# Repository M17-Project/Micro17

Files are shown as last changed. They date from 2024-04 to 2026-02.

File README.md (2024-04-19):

[][cc-by-nc-sa]

# Micro17
M17 baseband processor board - OpenRTX on a Module.
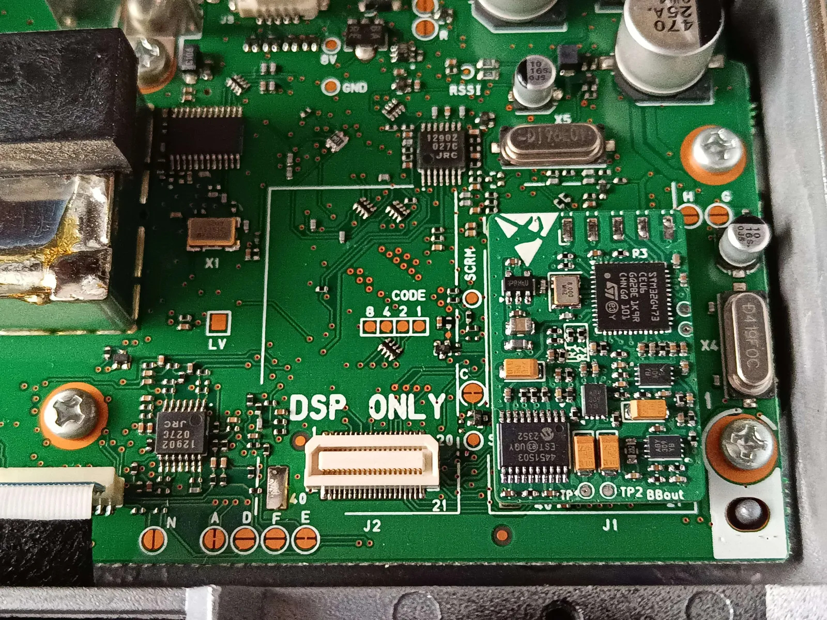
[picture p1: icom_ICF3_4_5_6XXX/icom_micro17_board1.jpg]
Micro17 connected to an ICOM radio.


## What is this?
Micro17 is an integrated implementation of Module17. Its PCB design is radio-dependent, but the general schematic is quite close to Module17. 
For more info about M17 and Module17, please checkout [M17's Website](https://m17project.org/) and [Module17's Github](https://github.com/M17-Project/Module_17) .

## Supported radios - variants
|Brand/Models|Status|
|---|---|
|[Generic (for all radios, can be used with modwires)](/generic/)|Hardware design WIP|
|[ICOM IC-F3XXX/4XXX/5XXX/6XXX](/icom_ICF3_4_5_6XXX/)|PoC OK, hardware design finished, fw WIP|
|[Motorola Waris (GM340/360/etc.)](/moto_waris/)|PoC OK, hardware design WIP|

## Adding support for other models
Do you have a radio that could be compatible with such an implementation? 
Any header (or ribbon cable connector) inside with the following pins can be used:
 - Flat audio in/out
 - Micro/Speaker lines
 - PTT in/out
 - Power supply 
 - (nice to have) command lines for interfacing with the radio's CPU
 
Very often, commercial radios with a scrambling board option have such lines inside. A Module17 modem is a perfect base to test a Proof of Concept before starting hardware design.
When creating a new variant of Micro17, you can use the "generic" variant as a working base, just copy and rename that folder.

## License
This work is licensed under a
[Creative Commons Attribution-NonCommercial-ShareAlike 4.0 International License][cc-by-nc-sa].

[][cc-by-nc-sa]

[cc-by-nc-sa]: http://creativecommons.org/licenses/by-nc-sa/4.0/
[cc-by-nc-sa-image]: https://licensebuttons.net/l/by-nc-sa/4.0/88x31.png
[cc-by-nc-sa-shield]: https://img.shields.io/badge/License-CC%20BY--NC--SA%204.0-lightgrey.svg

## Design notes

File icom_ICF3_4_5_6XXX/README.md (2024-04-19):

# Micro17 - IC-F3/4/5/6X6X
Variant of Micro17 for ICOM IC-F commercial radios. Compatible model list is available [here](/icom_ICF3_4_5_6XXX/general_info.md).
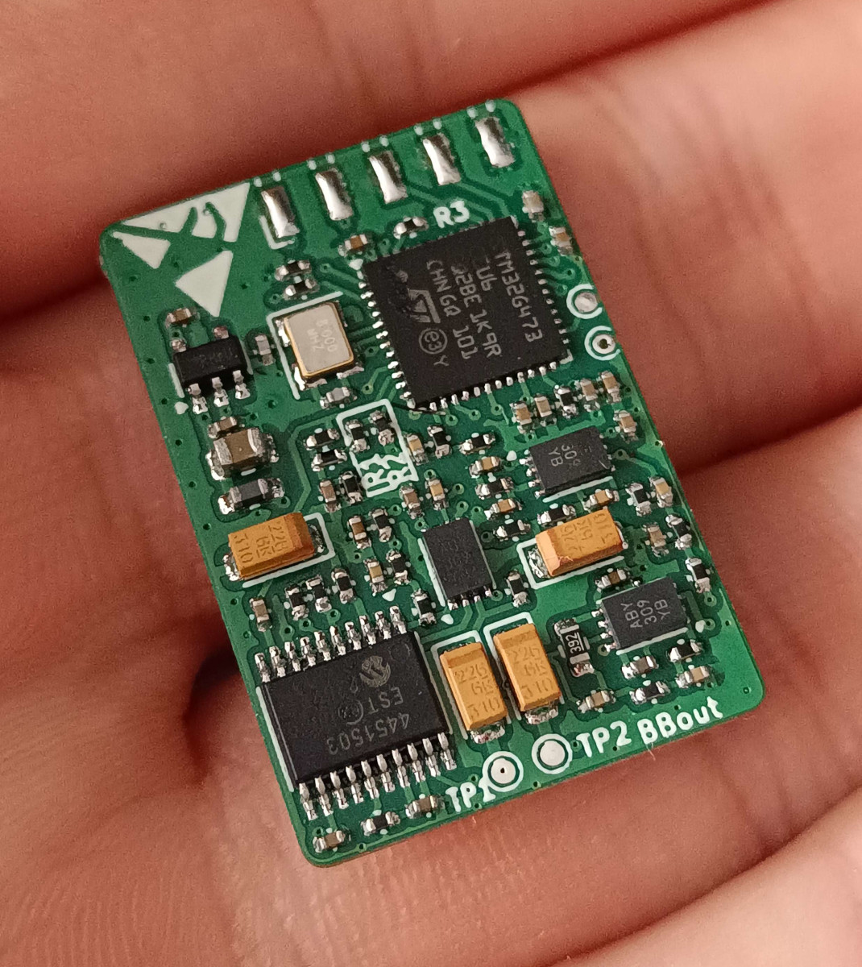
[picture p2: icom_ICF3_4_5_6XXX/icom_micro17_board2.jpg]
Micro17 connected to an ICOM radio.

## Flashing OpenRTX
WIP - ST-Link needed

## Installing Micro17 inside the radio
A Youtube video guide is planned soon:tm:. 
### Mobiles
Getting inside mobile IC-F5X6X/6X6X is quite straightforward: four screws will allow you to pop the bottom cover off. 
You'll need to cut/solder the following bridges:
* Cut "K", "A", "B" and "C"
* Solder/bridge "L"

You can then install Micro17 in the J1 slot. 
Micro17 connected to an ICOM radio.
### Handsets
Opening a handset is a bit trickier. You'll need to remove the two knobs, unscrew the antenna nut (either using thin needle-nose pliers or the appropriate tool. Be careful as it might be glued, some light blasting with a heat gun might be needed) and the two bottom screws behind the battery. 
The following bridges will have to be changed: 
* Cut "CP2", "MIC", "AFOUT" and "PTT" 
* Solder/bridge  "CP3"
You can then install Micro17 in the J1 slot.

## Configuring Micro17
As this module is embedded inside the radio, configuration is pulled from the radio's "codeplug". This is still heavily WIP, but it's planned to use the internal command protocol one the details get figured out. 

## Wiring details
This variant is based on the experiments documented [here](https://wiki.m17project.org/icf5060_3060). 
The internal J1 connector breaks out all necessary pins.
| **Module17 equivalent Pins** | **J1 connector** |
|---|---|
| GND (DB9 - pin 8) | Pin 2, 17 or 39 - GND |
| +12V/+8V (DB9 - pin 9) | Pin 37 - VCC |
| RX (DB9 - pin 6) | Pin 31 - DISC |
| TX (DB9 - pin 2) | Pin 13 - SIGO |
| PTT_OUT (DB9 - pin 5) | Pin 4 - PTTO (Add a 1K pullup to 5V - pin 38!) |
| AF_OUT (pot middle pin) | Pin 30 - AFOUT |
| MIC_IN (jack's middle pin) | Pin 7 - MCIN |
| PTT_IN (jack's last pin) | Pin 3 - PTTIN (Through a resistive divider: two 2.7k resistors in series between pins 2 and 3, wire to Module17 in the middle) |

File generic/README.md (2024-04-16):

# Micro17 - Generic

Generic variant of Micro17 for any radio.
This is still a simple copy of the ICOM version of this board. Just don't place the connector and solder to the test pads. 

## Flashing OpenRTX
WIP - ST-Link needed

## Installing Micro17 inside the radio
All up to you! Kynar modwires will be your best friend here.

## Configuring Micro17
As this module is embedded inside the radio, you'll have to either statically set your callsign inside the radio, or figure out a way to pull data from the radio's "codeplug"

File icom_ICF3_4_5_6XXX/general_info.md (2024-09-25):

# General information on ICOM IC-FXX6X radios
Almost every variation of the IC-FXX6X should be compatible with Micro17. 

## Model numbering
The model number will help you in identifying which version you have.
It is composed of 4 digits and one or more letters.
### First digit
* 5: Mobile VHF
* 6: Mobile UHF
* 3: Handset VHF
* 6: Handset UHF
  
### Second digit
* 0: compatible
* 1: compatible
* 2: __completely different revision, not compatible__

### Third digit
Only 6 is compatible

### Fourth digit
Market segment: 
* 1: USA
* 2: European Market
* 3: General
  
Be careful as there are US market models (suffix "1") that are 450-520, and others 400-470. I've managed to bring 450 models down to 434MHz, but it makes things quite complicated. Identifying them requires checking the FCC ID in the database, it'll give you the frequency range (handset numbers AFJ289402: 450-520MHz, AFJ289401: 400-470MHz). 

### Letter suffixes:
* T: 10-key version
* S: for a 4 key version
* D: digital (with an additional UT-126 board for NXDN and dPMR support. Basically the exact same radio with an additional removable board).
  
A 4-key version can be case-swapped with a 10 key version without issues. The UT-126 is completely unnecessairy for this M17 mod. Removing it might be a good idea to reduce battery usage. 

### Common examples
In UHF, the IC-F6061 mobile is quite common on eBay. If you're in Europe, you might get lucky and score an IC-F6062. For handsets, the IC-F4161DS pops up a lot.

## Programming the radios
Those radios are channelized, and will require you to program your frequencies one way or another. If you're lucky, you'll be able to program it via the front panel [using this procedure](https://sawback.com/wp-content/uploads/2018/11/Icom-Front-Panel-Programming.pdf) (the combination to trigger programming mode is slightly different: P0 and the button above PTT). 
Otherwise, you'll need the cloning software (a quick google search should help you out) and the programming cable:
* For the handsets, you'll need to buy the cable, cheap clones are available on [Aliexpress](https://www.aliexpress.com/item/1005001671445899.html).
* For the mobiles, Aliexpress can also be your friend... You can also make your own cable using an RJ45 connector and a 5V USB-TTL adapter. Pin 2 goes to RXD, Pin 8 to TXD, Pin 7 to GND.

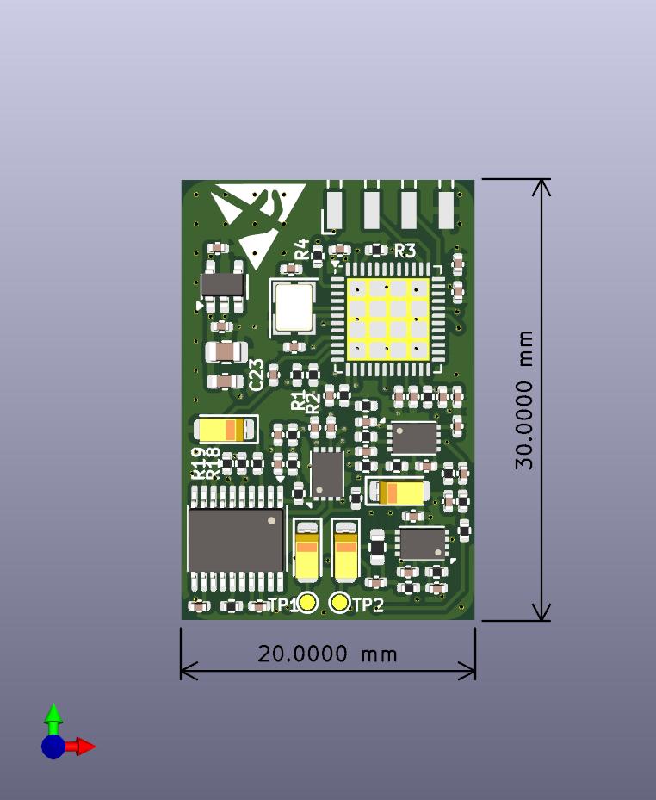
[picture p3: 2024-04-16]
generic/icom_micro17_design.jpg

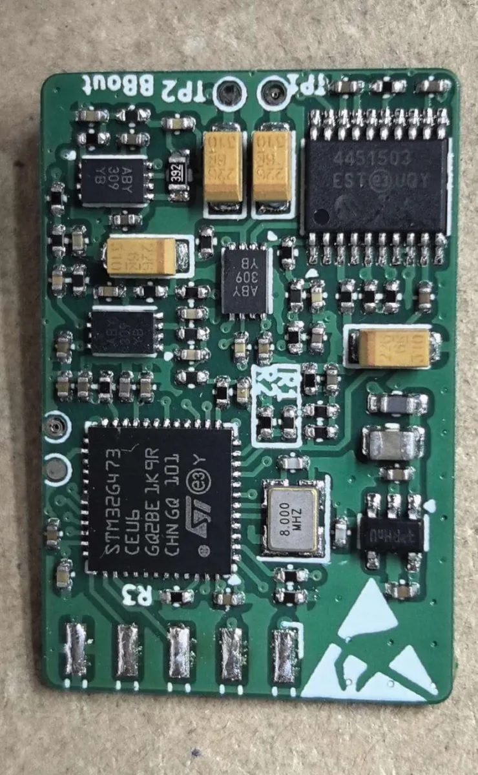
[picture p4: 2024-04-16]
generic/icom_micro17_board2.jpg

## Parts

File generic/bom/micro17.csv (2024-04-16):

Id | Designator | Footprint | Quantity | Designation | Supplier and ref
1 | R13,R23 | R_0402_1005Metric | 2 | 39k
2 | C19,C31,C20,C24,C29,C16,C14,C15 | C_0402_1005Metric | 8 | 10n
3 | R29,R2 | R_0402_1005Metric | 2 | 12k
4 | C28,C34,C26,C27 | CP_EIA-3216-18_Kemet-A | 4 | 22u
5 | R1 | R_0402_1005Metric | 1 | 36k
6 | R10,R11 | R_0402_1005Metric | 2 | 7k5
7 | U2 | SOT-23-5 | 1 | XC6220B331MR
8 | R5 | R_0402_1005Metric | 1 | 10R
9 | R27,R20,R21,R17,R28,R26 | R_0402_1005Metric | 6 | 22k
10 | R16,R4,R3 | R_0402_1005Metric | 3 | 10k
11 | R9,R8 | R_0402_1005Metric | 2 | 13k
12 | C17,C18 | C_0402_1005Metric | 2 | 1n5
13 | C7,C13,C30,C6,C8,C35,C4,C5,C11,C33,C25 | C_0402_1005Metric | 11 | 100n
14 | R24 | R_0603_1608Metric | 1 | 3k9
15 | C12,C23,C22 | C_0402_1005Metric | 3 | 220n
16 | R14,R22,R19,R18 | R_0402_1005Metric | 4 | 3k3
17 | C32,C21 | C_0402_1005Metric | 2 | 680p
18 | U6,U4,U7 | DFN-8-1EP_3x2mm_P0.5mm_EP1.75x1.45mm | 3 | MCP6002
19 | C3 | C_0402_1005Metric | 1 | 2u2
20 | C2,C1 | C_0402_1005Metric | 2 | 2p2
21 | U5 | TSSOP-20_4.4x6.5mm_P0.65mm | 1 | MCP4451-503-ST
22 | C10 | C_0805_2012Metric | 1 | 22u/25V
23 | U1 | QFN-48-1EP_7x7mm_P0.5mm_EP5.6x5.6mm | 1 | STM32G473CCUx
24 | C9 | C_0402_1005Metric | 1 | 1u
25 | R12 | R_0402_1005Metric | 1 | 3k9
26 | FB1 | L_0603_1608Metric_Pad1.05x0.95mm_HandSolder | 1 | FerriteBead_Small
27 | Y1 | Crystal_SMD_3225-4Pin_3.2x2.5mm | 1 | 8 MHz
28 | R15 | R_0402_1005Metric | 1 | 2k2
29 | R6,R7 | R_0402_1005Metric | 2 | 4k3
30 | J2 | AXK640347YG | 1 | AXK640347YG

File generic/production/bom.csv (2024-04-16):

Designator | Footprint | Quantity | Value | LCSC Part #
C1, C2 | 0402 | 2 | 2p2 | C1559
C10 | 0805 | 1 | 22u/25V | C45783
C11, C13, C25, C30, C33, C35, C4, C5, C6, C7, C8 | 0402 | 11 | 100n | C56392
C12, C22, C23 | 0402 | 3 | 220n | C192432
C14, C15, C16, C19, C20, C24, C29, C31 | 0402 | 8 | 10n | C60133
C17, C18 | 0402 | 2 | 1n5 | C284989
C21, C32 | 0402 | 2 | 680p | C1541
C26, C27, C28, C34 | CP_EIA-3216-18_Kemet-A | 4 | 22u | C118989
C3 | 0402 | 1 | 2u2 | C170151
C9 | 0402 | 1 | 1u | C29266
FB1 | 0603 | 1 | FerriteBead_Small | C2971885
J2 | AXK640347YG | 1 | AXK640347YG | C2936870
R1 | 0402 | 1 | 36k | C4354982
R10, R11 | 0402 | 2 | 7k5 | C2960875
R12 | 0402 | 1 | 3k9 | C3015806
R13, R23 | 0402 | 2 | 39k | C25783
R14, R18, R19, R22 | 0402 | 4 | 3k3 | C25890
R15 | 0402 | 1 | 2k2 | C102890
R16, R3, R4 | 0402 | 3 | 10k | C102749
R17, R20, R21, R26, R27, R28 | 0402 | 6 | 22k | C2909337
R2, R29 | 0402 | 2 | 12k | C25752
R24 | 0603 | 1 | 3k9 | C23018
R5 | 0402 | 1 | 10R | C854481
R6, R7 | 0402 | 2 | 4k3 | C25899
R8, R9 | 0402 | 2 | 13k | C25754
U1 | QFN-48-1EP_7x7mm_P0.5mm_EP5.6x5.6mm | 1 | STM32G473CCUx | C1342773
U2 | SOT-23-5 | 1 | XC6220B331MR | C3040644
U4, U6, U7 | DFN-8-1EP_3x2mm_P0.5mm_EP1.75x1.45mm | 3 | MCP6002 | C623660
U5 | TSSOP-20_4.4x6.5mm_P0.65mm | 1 | MCP4451-503-ST | C627257
Y1 | Crystal_SMD_3225-4Pin_3.2x2.5mm | 1 | 8 MHz | C5308002

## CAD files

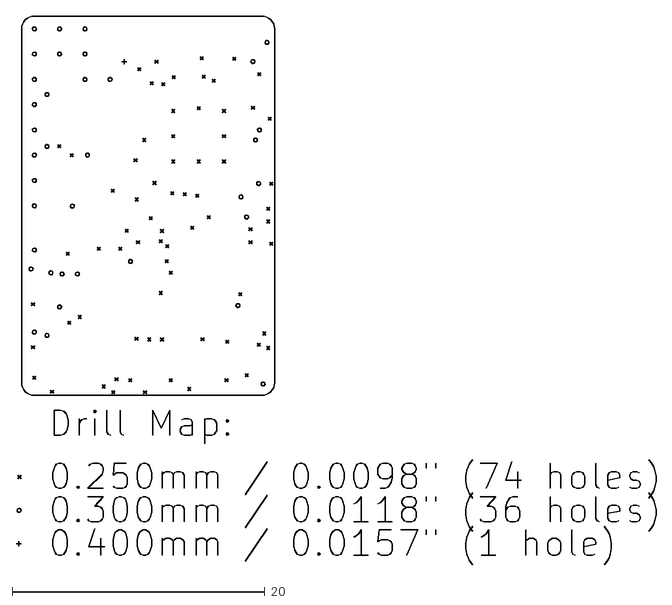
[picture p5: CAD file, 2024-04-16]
generic/Gerbers/micro17-PTH-drl_map.dxf
50.6 x 43.4

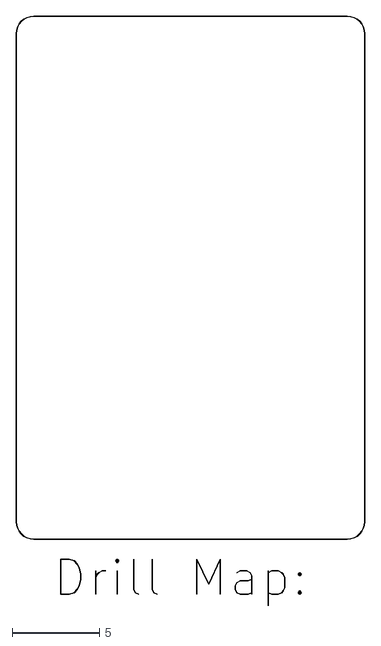
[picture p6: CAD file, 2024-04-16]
generic/Gerbers/micro17-NPTH-drl_map.dxf
20.0 x 33.8

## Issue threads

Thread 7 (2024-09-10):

DAC doesn't work - stuck at 0V

sp5wwp, 2024-09-10:
`VREF+` pin is left floating. Connect it with `VDDA`.

Workaround: put a solder blob across pins 20 and 21.

sp5wwp, 2025-06-13:
Fixed in [005c063](https://github.com/M17-Project/Micro17/commit/005c063634e73d94ec628afa24ce1d9f97f03a83).

Closed 2025-06-13.

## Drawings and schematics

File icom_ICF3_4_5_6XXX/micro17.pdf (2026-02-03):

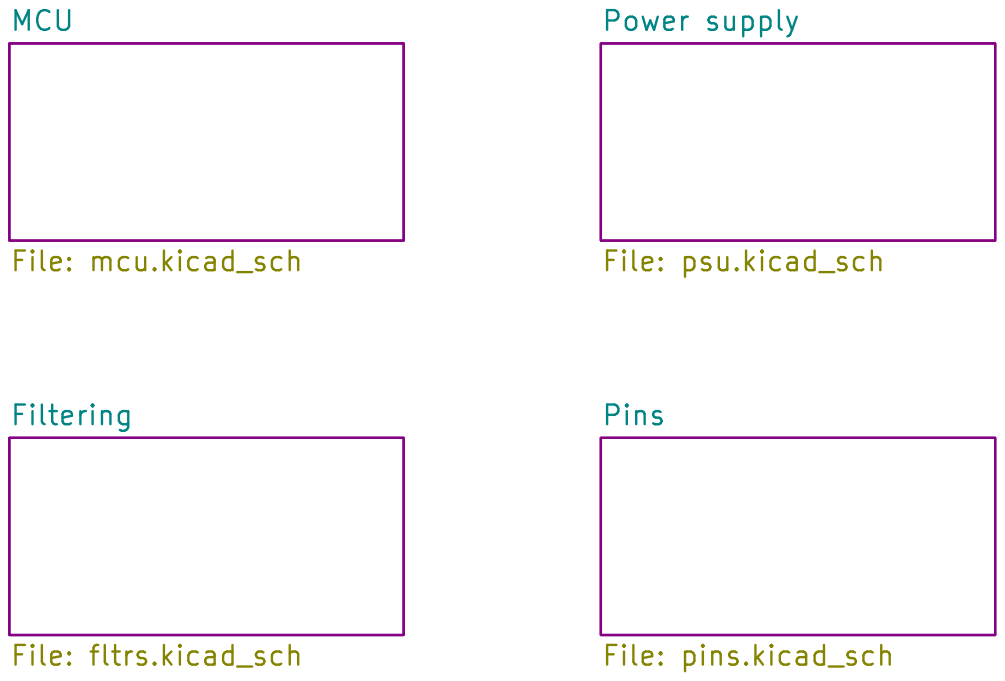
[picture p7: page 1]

Power supply File: psu.kicad_sch Pins File: pins.kicad_sch

Filtering File: fltrs.kicad_sch MCU

Id: 1/5 Title: Micro17 - OpenRTX on a Module for ICOM radios

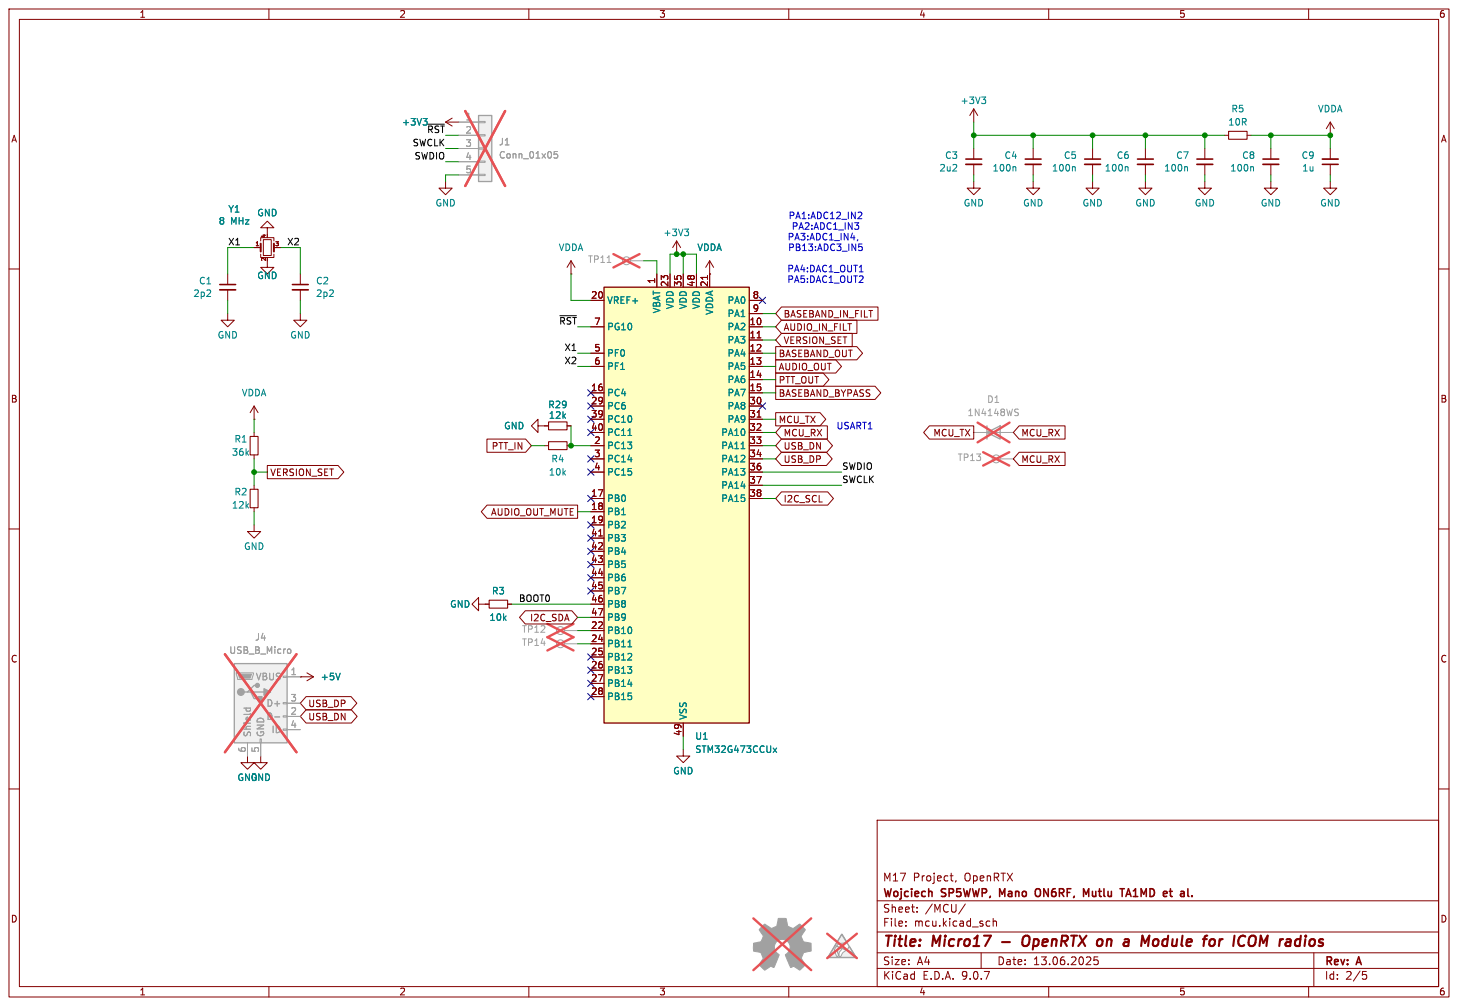
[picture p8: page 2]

1 VDD 23 VDD 35 VSS 49 VDD 48 VDDA 21 PA0 8 PA1 9 PA2 10 PA3 11 PA4 12 PA5 13 PA6 14 PA7 15 PA8 30 PA9 31 PA10 32 PA11 33 PA12 34 PA13 36 PA14 37 PA15 38 U1STM32G473CCUx D1

1 VDD 23 VDD 35 VSS 49 VDD 48 VDDA 21 PA0 8 PA1 9 PA2 10 PA3 11 PA4 12 PA5 13 PA6 14 PA7 15 PA8 30 PA9 31 PA10 32 PA11 33 PA12 34 PA13 36 PA14 37 PA15 38 GND

Id: 2/5 Title: Micro17 - OpenRTX on a Module for ICOM radios

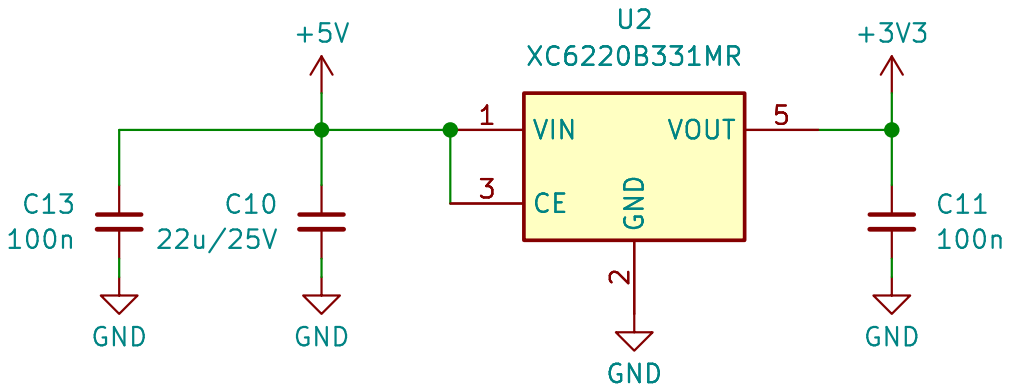
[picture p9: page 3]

Id: 3/5 Title: Micro17 - OpenRTX on a Module for ICOM radios

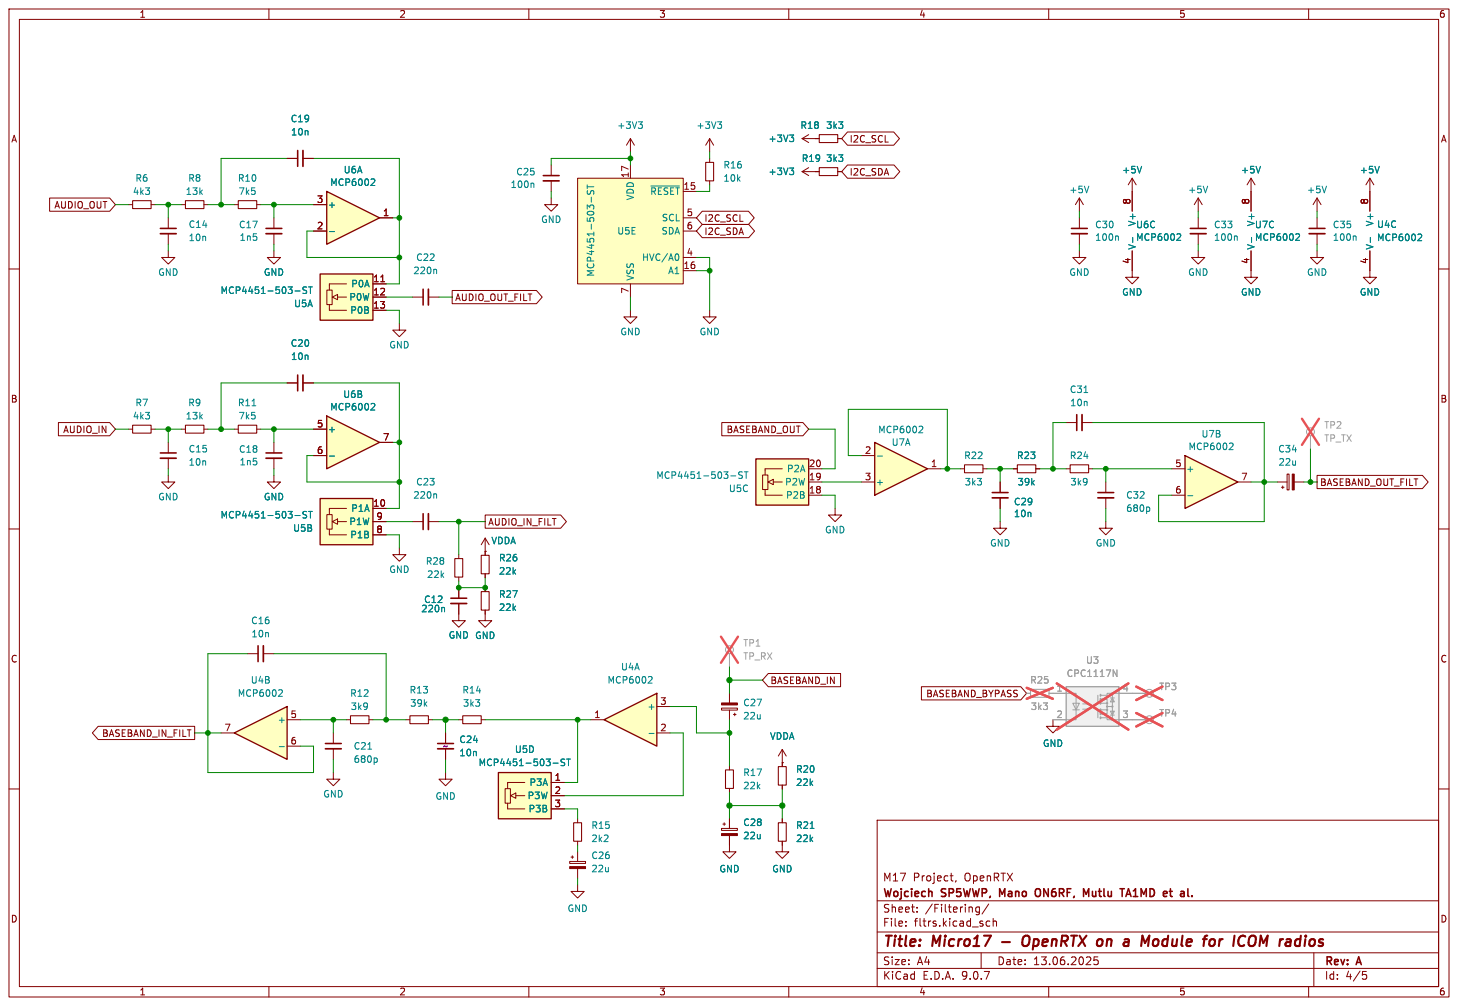
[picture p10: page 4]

File: fltrs.kicad_sch Sheet: /Filtering/
Id: 4/5 Title: Micro17 - OpenRTX on a Module for ICOM radios

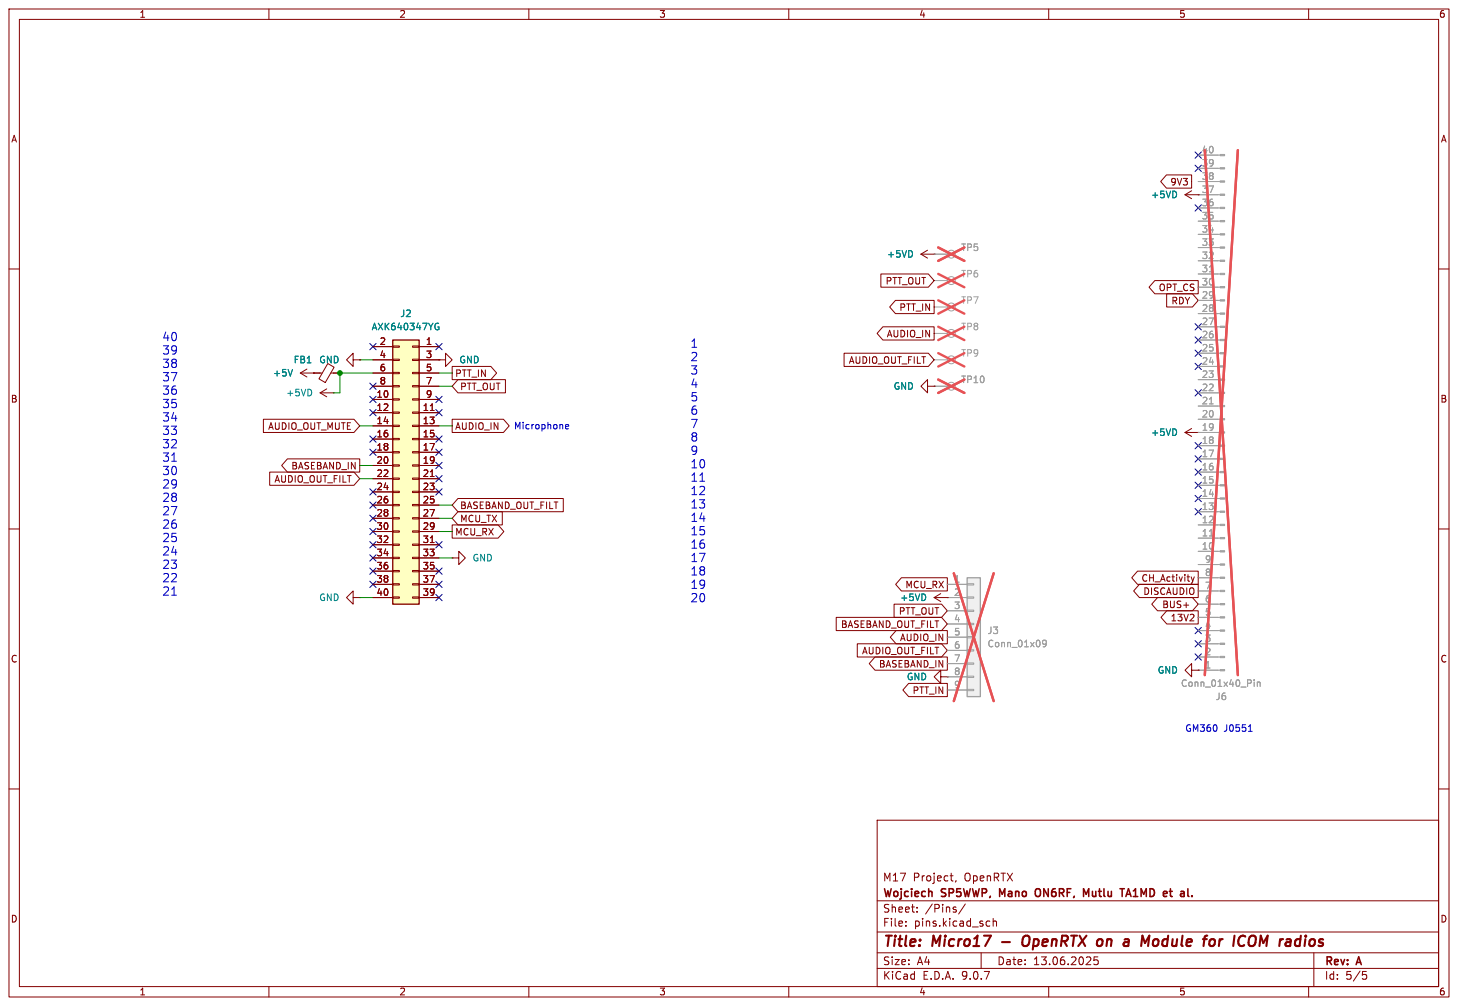
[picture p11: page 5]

Id: 5/5 Title: Micro17 - OpenRTX on a Module for ICOM radios

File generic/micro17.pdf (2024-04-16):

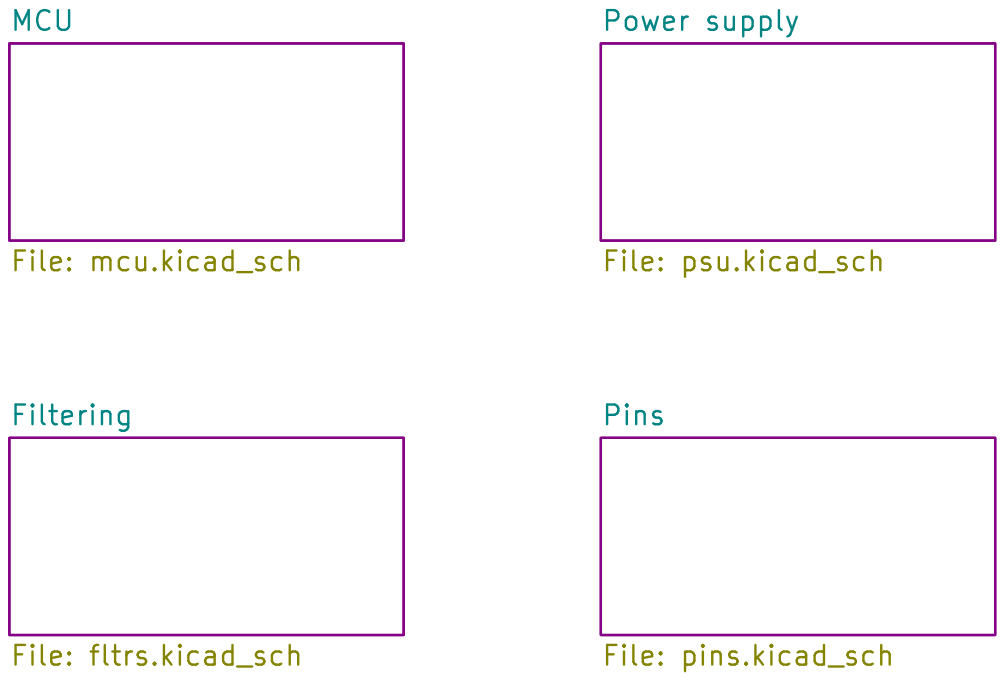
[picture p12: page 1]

Power supply File: psu.kicad_sch Pins File: pins.kicad_sch

Filtering File: fltrs.kicad_sch MCU

Id: 1/5 Title: Micro17 - OpenRTX on a Module for ICOM radios

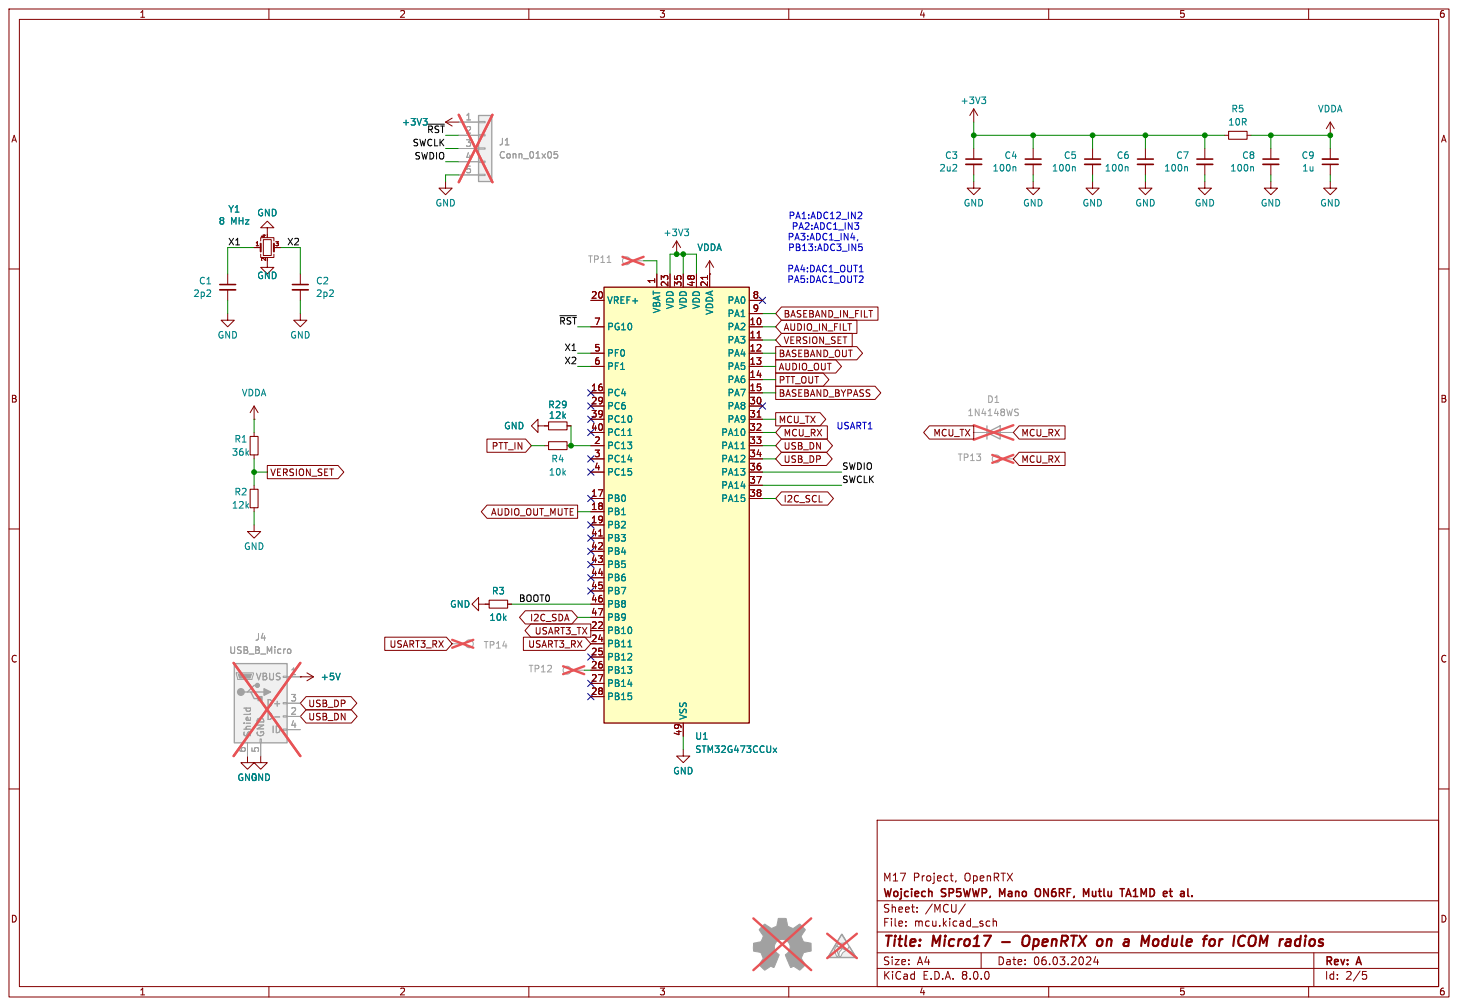
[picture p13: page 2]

1 PA2 10 PA3 11 PA4 12 PA5 13 PA6 14 PA7 15 PC4 16 PB0 17 PB1 18 PB2 19 PC13 2 VREF+ 20 VDDA 21 PB10 22 VDD 23 PB11 24 PB12 25 PB13 26 PB14 27 PB15 28 PC6 29 PC14 3 PA8 30 PA9 31 PA10 32 PA11 33 PA12 34 VDD 35 PA13 36 PA14 37 PA15 38 PC10 39 PC15 4 PC11 40 PB3 41 PB4 42 PB5 43 PB6 44 PB7 45 PB8 46 PB9 47 VDD 48 VSS 49 PF0 5 PF1 6 PG10 7 PA0 8 PA1 9 U1STM32G473CCUx R4

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

Id: 2/5 Title: Micro17 - OpenRTX on a Module for ICOM radios

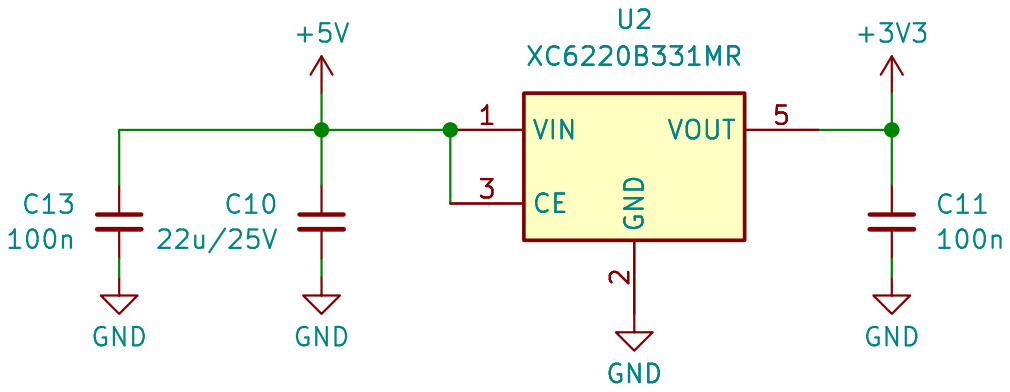
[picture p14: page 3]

Id: 3/5 Title: Micro17 - OpenRTX on a Module for ICOM radios

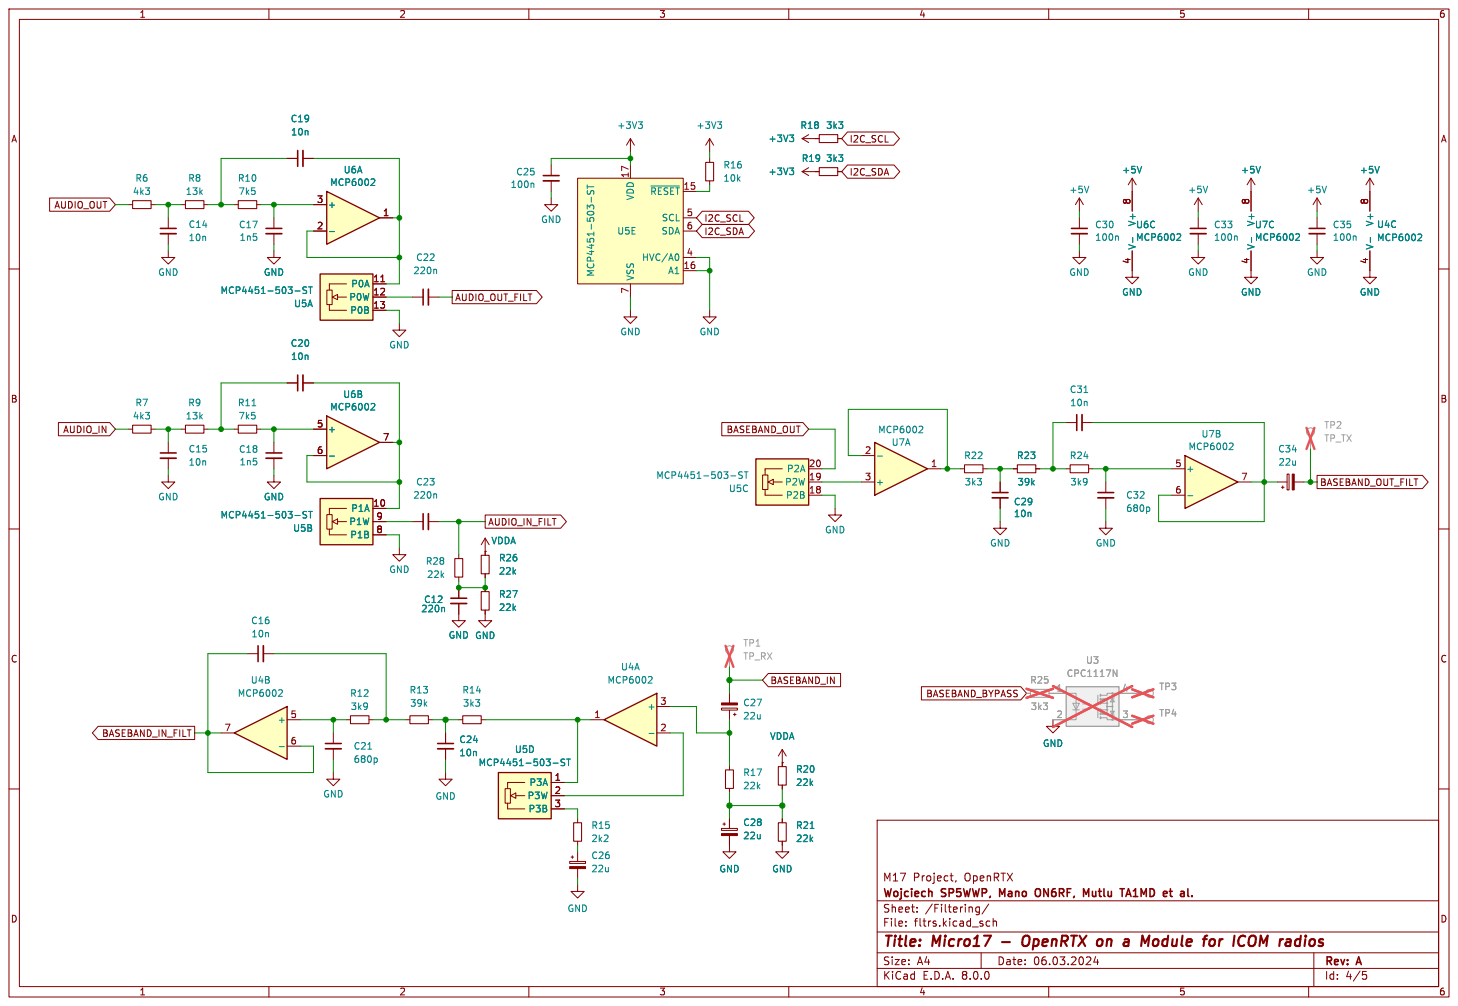
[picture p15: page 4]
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

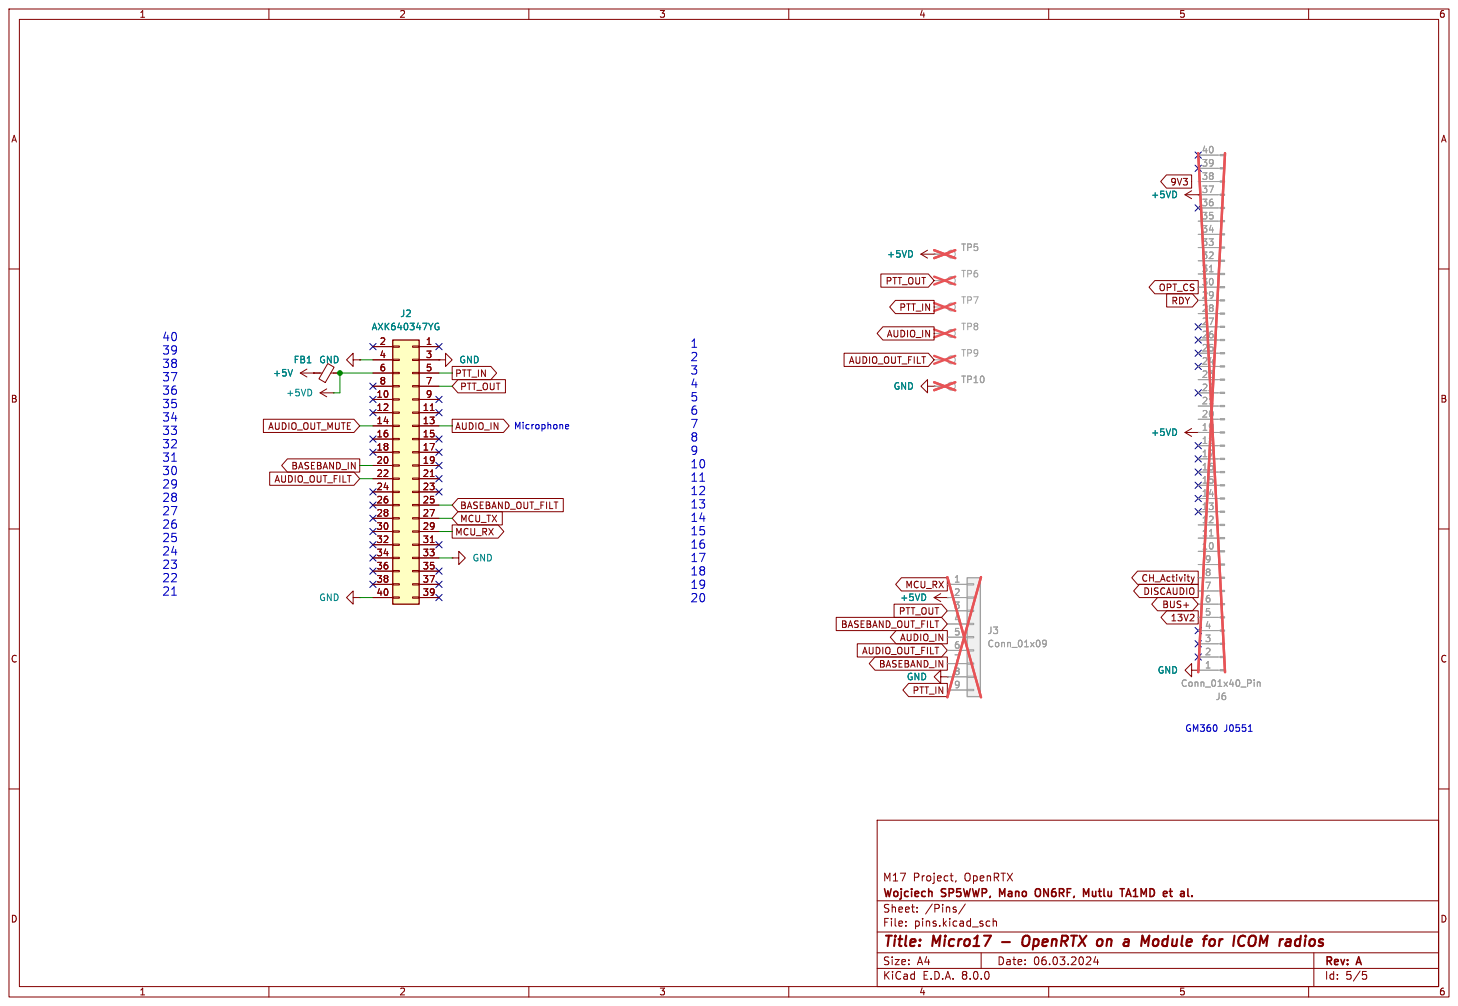
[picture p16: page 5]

Id: 5/5 Title: Micro17 - OpenRTX on a Module for ICOM radios

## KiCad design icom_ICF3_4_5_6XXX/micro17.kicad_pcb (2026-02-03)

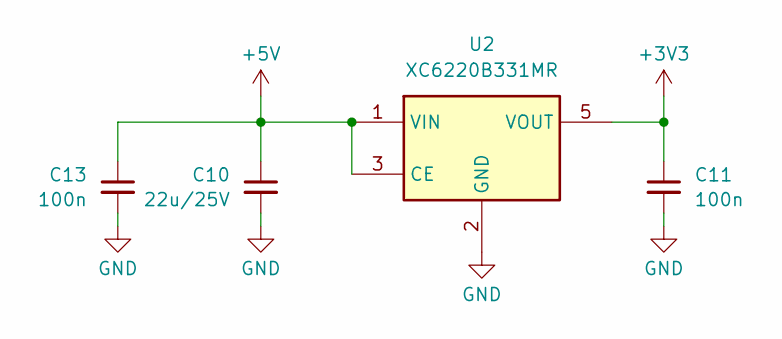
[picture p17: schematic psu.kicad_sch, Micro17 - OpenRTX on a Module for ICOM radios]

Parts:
C10: 22u/25V; C_0805_2012Metric; MPN C45783; LCSC C45783
C11, C13: 100n; C_0402_1005Metric; MPN C56392; LCSC C56392
U2: XC6220B331MR; SOT-23-5; MPN C3040644; LCSC C3040644

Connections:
+3V3: C11.1, U2.5 (VOUT); also elsewhere on the board
+5V: C10.1, C13.1, U2.1 (VIN), U2.3 (CE); also elsewhere on the board
GND: C10.2, C11.2, C13.2, U2.2 (GND); also elsewhere on the board

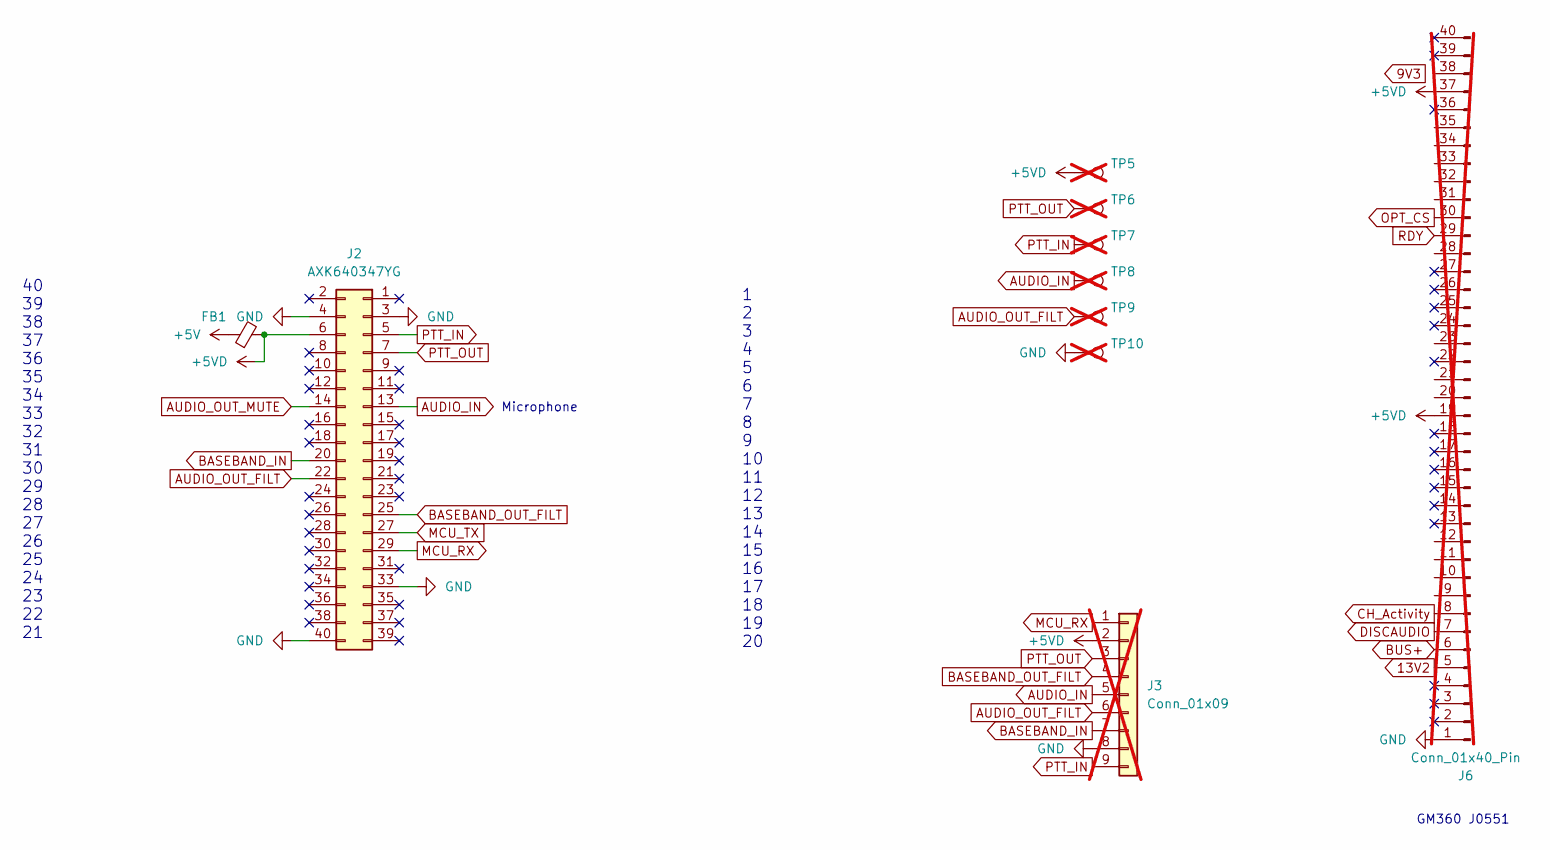
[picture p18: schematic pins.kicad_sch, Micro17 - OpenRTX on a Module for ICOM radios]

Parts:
FB1: FerriteBead_Small; L_0603_1608Metric_Pad1.05x0.95mm_HandSolder; MPN C2971885; LCSC C2971885
J2: AXK640347YG; MPN C2936870; LCSC C2936870
J3: Conn_01x09; PinSocket_1x09_P2.00mm_Horizontal; not fitted
J6: Conn_01x40_Pin; Hirose_FH12-40S-0.5SH_1x40-1MP_P0.50mm_Horizontal; not fitted
TP5, TP6, TP7, TP8, TP9, TP10: GP; TestPoint_Pad_D1.0mm; not fitted

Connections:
+5V: FB1.1; also elsewhere on the board
+5VD: FB1.2, J2.6, J3.2, J6.19, J6.37, TP5.1
AUDIO_IN: J2.13, J3.5, TP8.1; also elsewhere on the board
AUDIO_OUT_FILT: J2.22, J3.6, TP9.1; also elsewhere on the board
AUDIO_OUT_MUTE: J2.14; also elsewhere on the board
BASEBAND_IN: J2.20, J3.7; also elsewhere on the board
BASEBAND_OUT_FILT: J2.25, J3.4; also elsewhere on the board
GND: J2.3, J2.4, J2.33, J2.40, J3.8, J6.1, TP10.1; also elsewhere on the board
MCU_RX: J2.29, J3.1; also elsewhere on the board
MCU_TX: J2.27; also elsewhere on the board
PTT_IN: J2.5, J3.9, TP7.1; also elsewhere on the board
PTT_OUT: J2.7, J3.3, TP6.1; also elsewhere on the board

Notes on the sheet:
GM360 J0551
Microphone
40 39 38 37 36 35 34 33 32 31 30 29 28 27 26 25 24 23 22 21
1 2 3 4 5 6 7 8 9 10 11 12 13 14 15 16 17 18 19 20

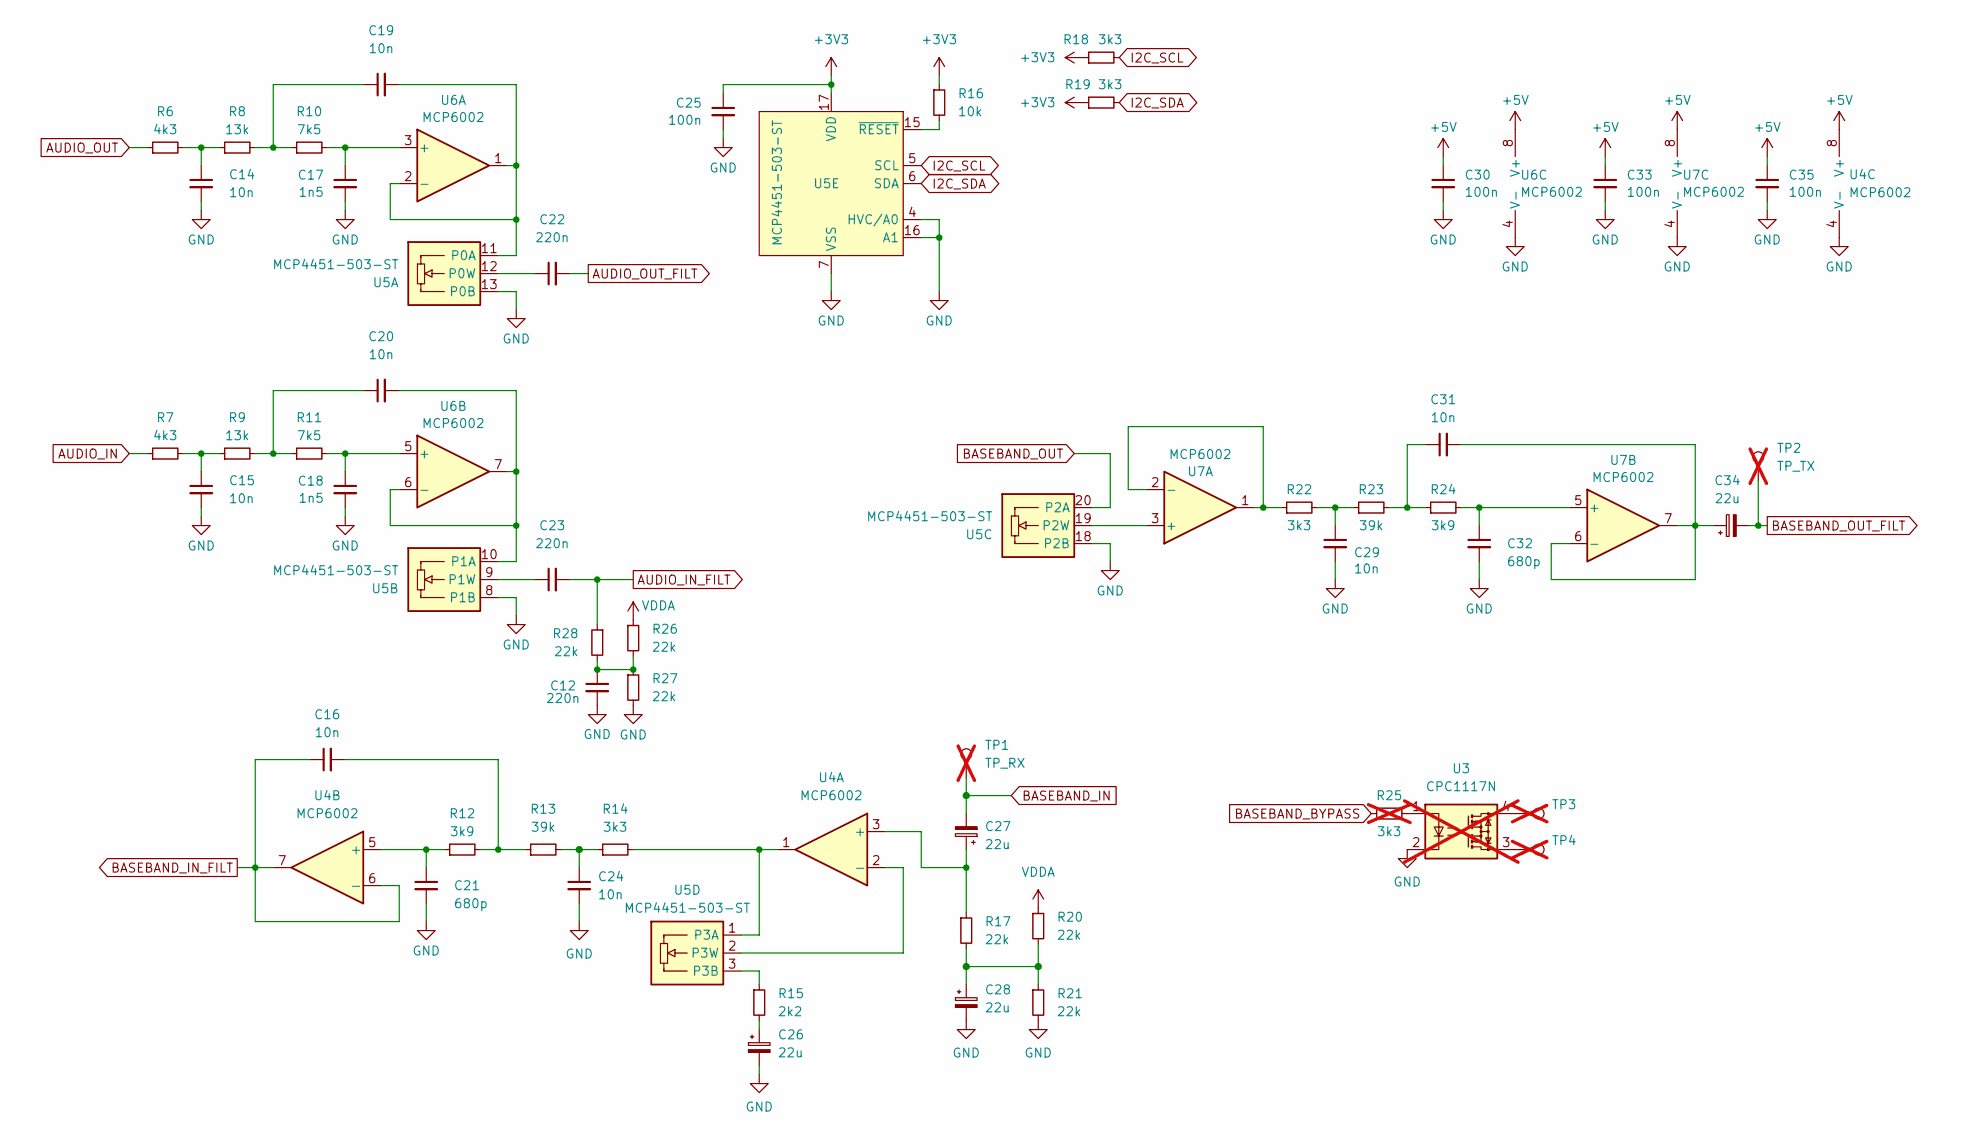
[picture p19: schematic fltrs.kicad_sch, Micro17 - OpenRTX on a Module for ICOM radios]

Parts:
C12, C22, C23: 220n; C_0402_1005Metric; MPN C192432; LCSC C192432
C14, C15, C16, C19, C20, C24, C29, C31: 10n; C_0402_1005Metric; MPN C60133; LCSC C60133
C17, C18: 1n5; C_0402_1005Metric; MPN C284989; LCSC C284989
C21, C32: 680p; C_0402_1005Metric; MPN C1541; LCSC C1541
C25, C30, C33, C35: 100n; C_0402_1005Metric; MPN C56392; LCSC C56392
C26, C27, C28, C34: 22u; CP_EIA-3216-18_Kemet-A; MPN C118989; LCSC C118989
R6, R7: 4k3; R_0402_1005Metric; MPN C25899; LCSC C25899
R8, R9: 13k; R_0402_1005Metric; MPN C25754; LCSC C25754
R10, R11: 7k5; R_0402_1005Metric; MPN C2960875; LCSC C2960875
R12: 3k9; R_0402_1005Metric; MPN C3015806; LCSC C3015806
R13, R23: 39k; R_0402_1005Metric; MPN C25783; LCSC C25783
R14, R18, R19, R22: 3k3; R_0402_1005Metric; MPN C25890; LCSC C25890
R15: 2k2; R_0402_1005Metric; MPN C102890; LCSC C102890
R16: 10k; R_0402_1005Metric; MPN C102749; LCSC C102749
R17, R20, R21, R26, R27, R28: 22k; R_0402_1005Metric; MPN C2909337; LCSC C2909337
R24: 3k9; R_0603_1608Metric; MPN C23018; LCSC C23018
R25: 3k3; R_0402_1005Metric; LCSC C25890; not fitted
TP1: TP_RX; TestPoint_Pad_D1.0mm; not fitted
TP2: TP_TX; TestPoint_Pad_D1.0mm; not fitted
TP3, TP4: GP; TestPoint_Pad_D1.0mm; not fitted
U3: CPC1117N; SOP-4_3.8x4.1mm_P2.54mm; not fitted
U4, U6, U7: MCP6002; DFN-8-1EP_3x2mm_P0.5mm_EP1.75x1.45mm; MPN C623660; LCSC C623660
U5: MCP4451-503-ST; TSSOP-20_4.4x6.5mm_P0.65mm; MPN C627257; LCSC C627257

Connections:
+3V3: C25.1, R16.1, R18.1, R19.1, U5.17 (VDD); also elsewhere on the board
+5V: C30.1, C33.1, C35.1, U4.8 (V+), U6.8 (V+), U7.8 (V+); also elsewhere on the board
AUDIO_IN: R7.1; also elsewhere on the board
AUDIO_IN_FILT: C23.2, R28.1; also elsewhere on the board
AUDIO_OUT: R6.1; also elsewhere on the board
AUDIO_OUT_FILT: C22.2; also elsewhere on the board
BASEBAND_BYPASS: R25.1; also elsewhere on the board
BASEBAND_IN: C27.2, TP1.1; also elsewhere on the board
BASEBAND_IN_FILT: C16.1, U4.6 (-), U4.7; also elsewhere on the board
BASEBAND_OUT: U5.20 (P2A); also elsewhere on the board
BASEBAND_OUT_FILT: C34.2, TP2.1; also elsewhere on the board
GND: C12.2, C14.2, C15.2, C17.2, C18.2, C21.2, C24.2, C25.2, C26.2, C28.2, C29.2, C30.2, C32.2, C33.2, C35.2, R21.2, R27.2, U3.2, U4.4 (V-), U4.9 (V-), U5.4 (HVC/A0), U5.7 (VSS), U5.8 (P1B), U5.13 (P0B), U5.16 (A1), U5.18 (P2B), U6.4 (V-), U6.9 (V-), U7.4 (V-), U7.9 (V-); also elsewhere on the board
I2C_SCL: R18.2, U5.5 (SCL); also elsewhere on the board
I2C_SDA: R19.2, U5.6 (SDA); also elsewhere on the board
unnamed: C12.1, R26.2, R27.1, R28.2
unnamed: C14.1, R6.2, R8.1
unnamed: C15.1, R7.2, R9.1
unnamed: C16.2, R12.2, R13.1
unnamed: C19.1, R8.2, R10.1
unnamed: C20.1, R9.2, R11.1
unnamed: C24.1, R13.2, R14.1
unnamed: C26.1, R15.2
unnamed: C28.1, R17.2, R20.2, R21.1
unnamed: C29.1, R22.2, R23.1
unnamed: C31.1, R23.2, R24.1
unnamed: R25.2, U3.1
unnamed: TP3.1, U3.4
unnamed: TP4.1, U3.3
unnamed: C27.1, R17.1, U4.3 (+)
unnamed: U4.2 (-), U5.2 (P3W)
unnamed: C21.1, R12.1, U4.5 (+)
unnamed: C19.2, U5.11 (P0A), U6.1, U6.2 (-)
unnamed: C22.1, U5.12 (P0W)
unnamed: C20.2, U5.10 (P1A), U6.6 (-), U6.7
unnamed: C23.1, U5.9 (P1W)
unnamed: U5.19 (P2W), U7.3 (+)
unnamed: R14.2, U4.1, U5.1 (P3A)
unnamed: R15.1, U5.3 (P3B)
unnamed: R16.2, U5.15 (~RESET)
unnamed: C17.1, R10.2, U6.3 (+)
unnamed: C18.1, R11.2, U6.5 (+)
unnamed: R22.1, U7.1, U7.2 (-)
unnamed: C32.1, R24.2, U7.5 (+)
unnamed: C31.2, C34.1, U7.6 (-), U7.7
VDDA: R20.1, R26.1; also elsewhere on the board

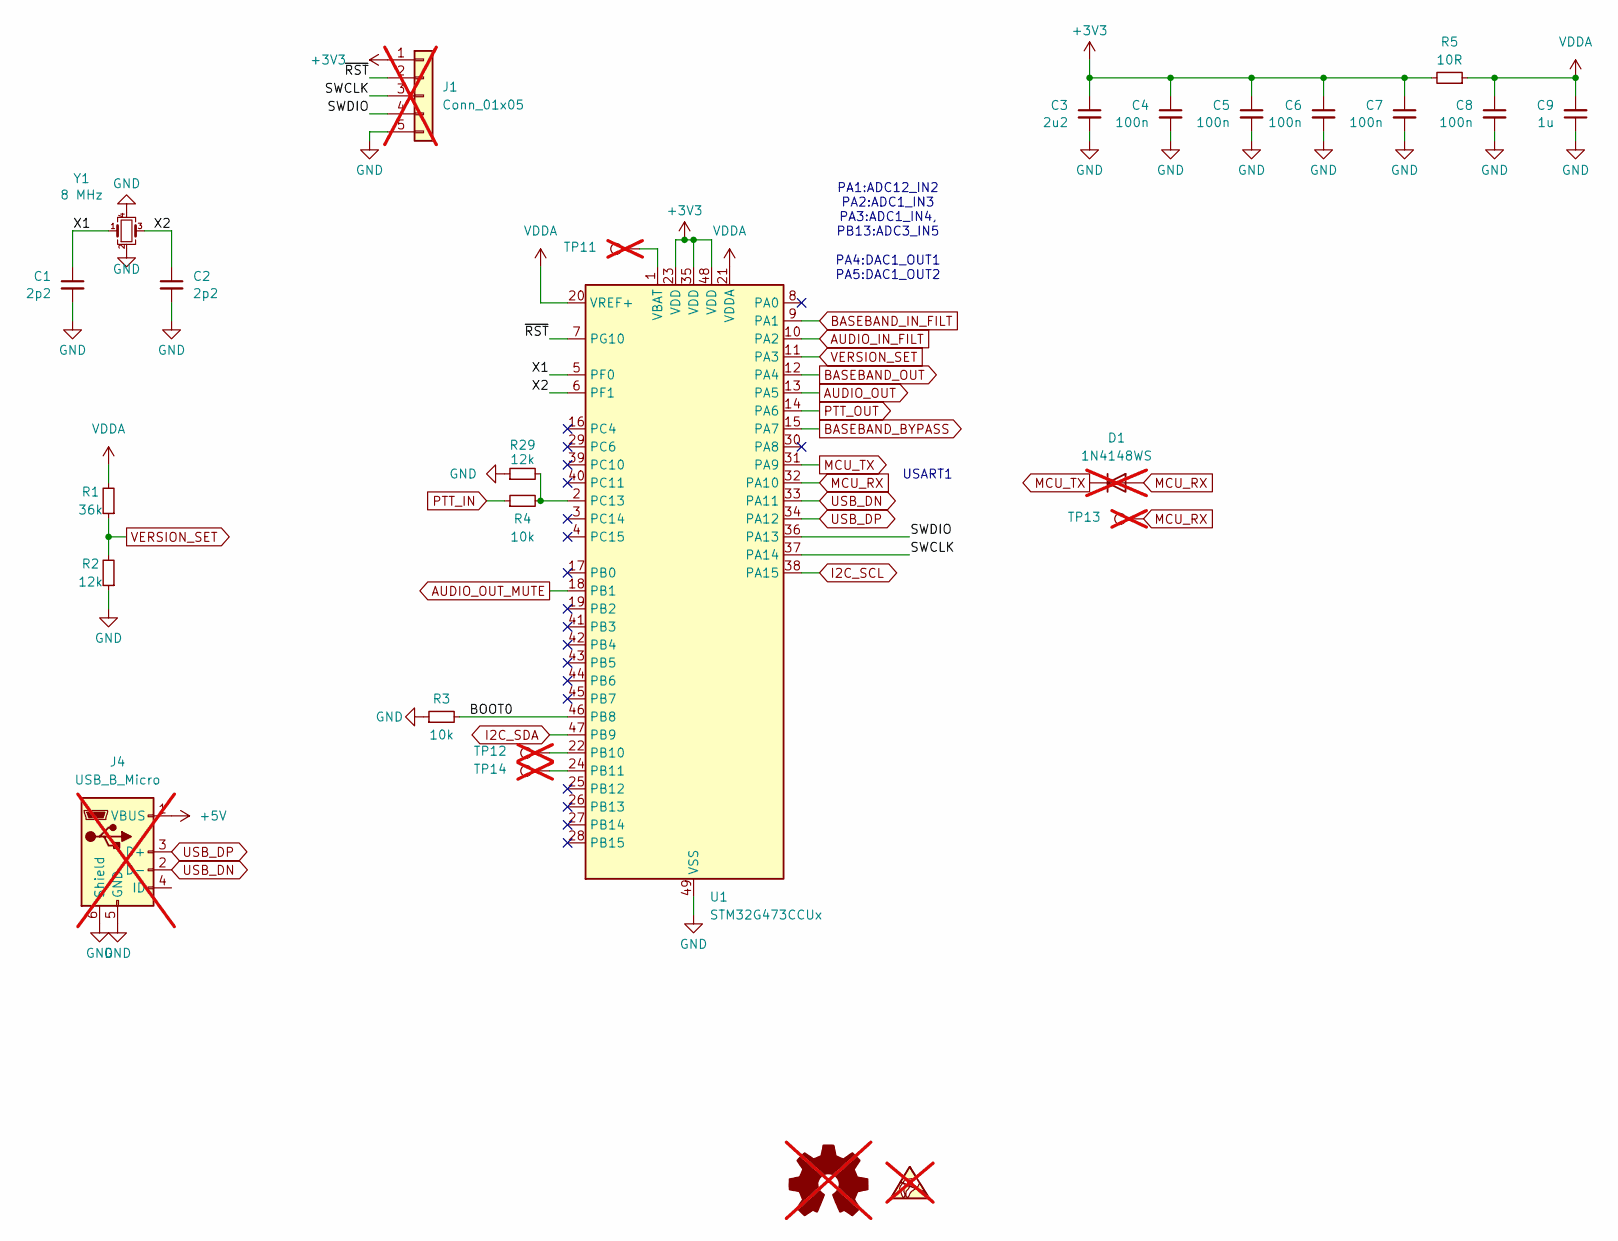
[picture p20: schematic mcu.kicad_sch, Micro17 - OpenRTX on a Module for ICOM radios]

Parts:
C1, C2: 2p2; C_0402_1005Metric; MPN C1559; LCSC C1559
C3: 2u2; C_0402_1005Metric; MPN C170151; LCSC C170151
C4, C5, C6, C7, C8: 100n; C_0402_1005Metric; MPN C56392; LCSC C56392
C9: 1u; C_0402_1005Metric; MPN C29266; LCSC C29266
D1: 1N4148WS; D_SOD-323; not fitted
J1: Conn_01x05; Harwin_M20-89005xx_1x05_P2.54mm_Horizontal; not fitted
J4: USB_B_Micro; USB_Micro-B_Molex_47346-0001; not fitted
R1: 36k; R_0402_1005Metric; MPN C4354982; LCSC C4354982
R2, R29: 12k; R_0402_1005Metric; MPN C25752; LCSC C25752
R3, R4: 10k; R_0402_1005Metric; MPN C102749; LCSC C102749
R5: 10R; R_0402_1005Metric; MPN C854481; LCSC C854481
SYM1: SYM_ESD_Small; ESD-Logo_6.6x6mm_SilkScreen; not fitted
SYM2: Logo_Open_Hardware_Small; OSHW-Logo_5.7x6mm_SilkScreen; not fitted
TP11, TP12, TP13, TP14: GP; TestPoint_Pad_D1.0mm; not fitted
U1: STM32G473CCUx; QFN-48-1EP_7x7mm_P0.5mm_EP5.6x5.6mm; MPN C1342773; LCSC C1342773
Y1: 8 MHz; Crystal_SMD_3225-4Pin_3.2x2.5mm; MPN C5308002; LCSC C5308002

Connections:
+3V3: C3.1, C4.1, C5.1, C6.1, C7.1, J1.1, R5.2, U1.23 (VDD), U1.35 (VDD), U1.48 (VDD); also elsewhere on the board
+5V: J4.1 (VBUS); also elsewhere on the board
/MCU/BOOT0: R3.2, U1.46 (PB8)
/MCU/SWCLK: J1.3, U1.37 (PA14)
/MCU/SWDIO: J1.4, U1.36 (PA13)
/MCU/X1: C1.1, U1.5 (PF0), Y1.1
/MCU/X2: C2.1, U1.6 (PF1), Y1.3
/MCU/~RST: J1.2, U1.7 (PG10)
AUDIO_IN_FILT: U1.10 (PA2); also elsewhere on the board
AUDIO_OUT: U1.13 (PA5); also elsewhere on the board
AUDIO_OUT_MUTE: U1.18 (PB1); also elsewhere on the board
BASEBAND_BYPASS: U1.15 (PA7); also elsewhere on the board
BASEBAND_IN_FILT: U1.9 (PA1); also elsewhere on the board
BASEBAND_OUT: U1.12 (PA4); also elsewhere on the board
GND: C1.2, C2.2, C3.2, C4.2, C5.2, C6.2, C7.2, C8.2, C9.1, J1.5, J4.5 (GND), J4.6 (Shield), R2.1, R3.1, R29.1, U1.49 (VSS), Y1.2, Y1.4; also elsewhere on the board
I2C_SCL: U1.38 (PA15); also elsewhere on the board
I2C_SDA: U1.47 (PB9); also elsewhere on the board
MCU_RX: D1.2 (A), TP13.1, U1.32 (PA10); also elsewhere on the board
MCU_TX: D1.1 (K), U1.31 (PA9); also elsewhere on the board
unnamed: TP12.1, U1.22 (PB10)
unnamed: TP14.1, U1.24 (PB11)
unnamed: R4.2, R29.2, U1.2 (PC13)
unnamed: TP11.1, U1.1 (VBAT)
PTT_IN: R4.1; also elsewhere on the board
PTT_OUT: U1.14 (PA6); also elsewhere on the board
USB_DN: J4.2 (D-), U1.33 (PA11)
USB_DP: J4.3 (D+), U1.34 (PA12)
VDDA: C8.1, C9.2, R1.2, R5.1, U1.20 (VREF+), U1.21 (VDDA); also elsewhere on the board
VERSION_SET: R1.1, R2.2, U1.11 (PA3)

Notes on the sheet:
USART1
PA1:ADC12_IN2 PA2:ADC1_IN3 PA3:ADC1_IN4, PB13:ADC3_IN5 PA4:DAC1_OUT1 PA5:DAC1_OUT2

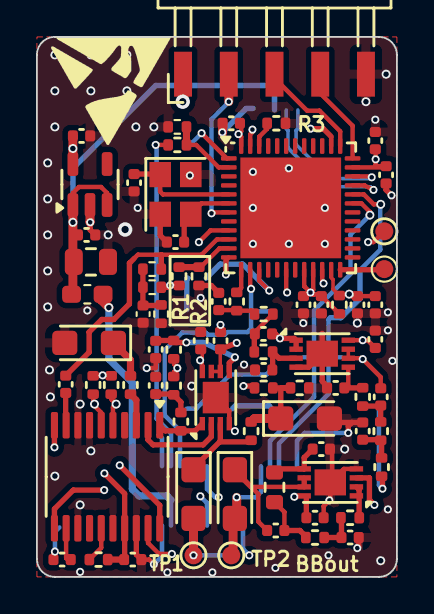
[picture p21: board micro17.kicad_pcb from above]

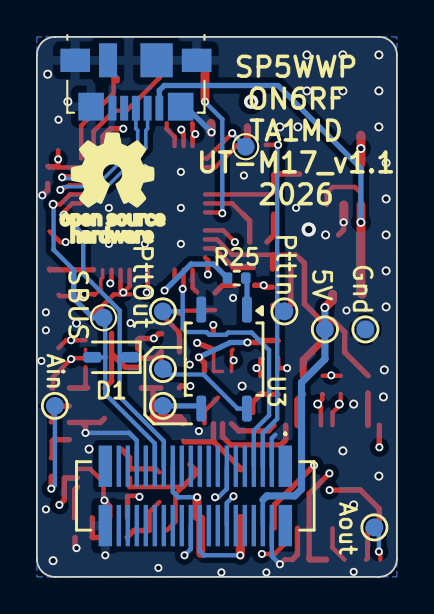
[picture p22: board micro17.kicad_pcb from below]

Board: 4 copper layers, 20.0 x 30.0 mm, 93 parts (16 on the bottom side), 64 nets.

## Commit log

2024-02-21 WIP filters
    [fltrs.kicad_sch, mcu.kicad_sch, psu.kicad_sch]
2024-02-26 First Edits
    Added J1 connector, finished filters and swapped µC to STM32G473
    [fltrs.kicad_sch, mcu.kicad_sch, micro17.kicad_pcb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]
2024-02-29 PCB routed, gerbers and ibom included
    [fltrs.kicad_sch, mcu.kicad_sch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]
2024-02-29 Updates
    GP relay added,
    3v3 added to programming conn.
    diode(dnp) added for motorola type internal bus.
    [fltrs.kicad_sch, mcu.kicad_sch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]
2024-02-29 LCSC part numbers included into schematics
    [fltrs.kicad_sch, mcu.kicad_sch, pins.kicad_sch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]
2024-03-02 J2 Corrected, More TP added.
    [mcu.kicad_sch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]
2024-03-04 PA2 Bias add, USB conn add.
    [fltrs.kicad_sch, mcu.kicad_sch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]
2024-03-04 Changed PA2 bias circuit
    [fltrs.kicad_sch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]
2024-03-04 Fixed some netlist overlaps and added a few mentions on readme.md
    [mcu.kicad_sch]
2024-03-04 added .pos and bom
    [micro17.csv]
2024-03-04 production files added.
    [bom.csv, designators.csv, positions.csv]
2024-03-06 cosmetic changes to the schematic layout
    - R25 - DNP
    - PDF render update
    [fltrs.kicad_sch, mcu.kicad_sch, micro17.kicad_pcb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]
2024-03-06 Bias voltage changed, usart rx tp add
    [bom.csv, designators.csv, fltrs.kicad_sch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]
2024-03-06 authors list fix
    [fltrs.kicad_sch]
2024-03-06 damned authors list
    [mcu.kicad_sch, pins.kicad_sch, psu.kicad_sch]
2024-04-16 Reorganized folder structure for variants
    Created one folder per variant, reworked the Readme.md for clarity.
    [bom.csv, designators.csv, fltrs.kicad_sch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]
2025-06-13 ICOM: fixed floating VREF+ pin
    KiCAD version bumped up to 9.0.2
    [fltrs.kicad_sch, mcu.kicad_sch, micro17.kicad_pcb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]
2026-02-03 re-routed debug UART
    [mcu.kicad_sch, micro17.kicad_pcb]

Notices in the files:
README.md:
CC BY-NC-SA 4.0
